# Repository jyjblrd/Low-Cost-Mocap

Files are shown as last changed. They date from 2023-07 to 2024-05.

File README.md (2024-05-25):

# Low Cost Mocap (for drones)

### A general purpose motion capture system built from the ground up, used to autonomously fly multiple drones indoors

## YouTube Video
Watch this for information about the project & a demo!
[https://youtu.be/0ql20JKrscQ?si=jkxyOe-iCG7fa5th](https://youtu.be/0ql20JKrscQ?si=jkxyOe-iCG7fa5th)

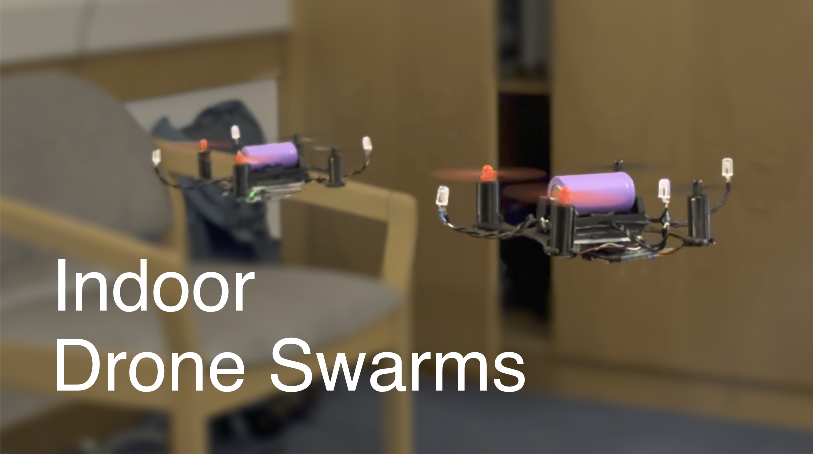
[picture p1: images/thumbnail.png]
[](https://youtu.be/0ql20JKrscQ?si=jkxyOe-iCG7fa5th)

## Architectural Diagram
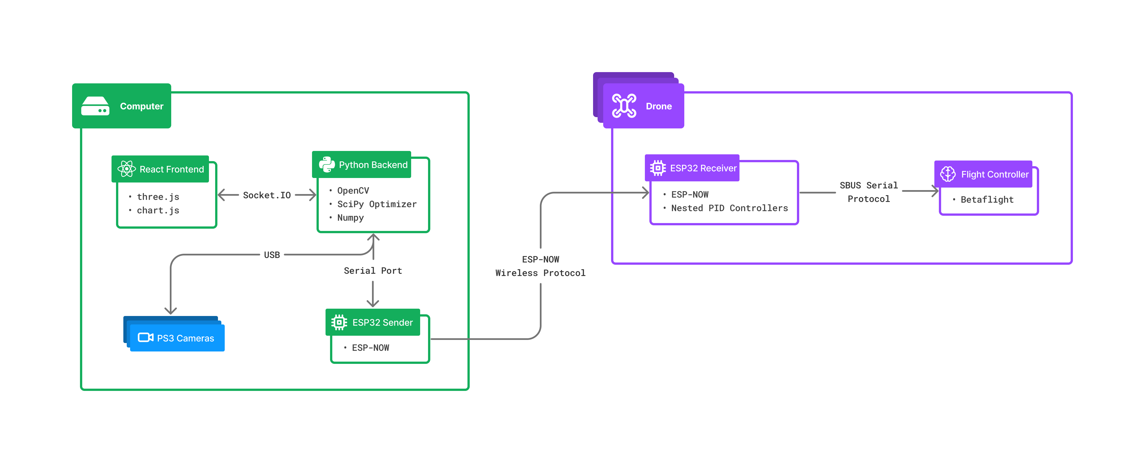
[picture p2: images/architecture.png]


## Dependencies
Install the pseyepy python library: [https://github.com/bensondaled/pseyepy](https://github.com/bensondaled/pseyepy)

This project requires the sfm (structure from motion) OpenCV module, which requires you to compile OpenCV from source[^1]. This is a bit of a pain, but these links should help you get started: [SFM dependencies](https://docs.opencv.org/4.x/db/db8/tutorial_sfm_installation.html) [OpenCV module installation guide](https://github.com/opencv/opencv_contrib/blob/master/README.md)

[^1]: ⚠️ The experimental [`no-cv-sfm`](https://github.com/jyjblrd/Low-Cost-Mocap/tree/no-cv-sfm) branch removes this OpenCV-SFM dependency, however it is *completely* untested. It is recommended to first try use the `main` branch which is tested, however feedback and bug reports on the `no-cv-sfm` branch are greatly appreciated. 

install npm and yarn

## Runing the code

From the computer_code directory Run `yarn install` to install node dependencies 

Then run `yarn run dev` to start the webserver. You will be given a url view the frontend interface.

In another terminal window, run `python3 api/index.py` to start the backend server. This is what receives the camera streams and does motion capture computations.

## Documentation
The documentation for this project is admittedly pretty lacking, if anyone would like to put type definitions in the Python code that would be amazing and probably go a long way to helping the readability of the code. Feel free to also use the [discussion](https://github.com/jyjblrd/Mocap-Drones/discussions) tab to ask questions.

My blog post has some more information about the drones & camera: [joshuabird.com/blog/post/mocap-drones](https://joshuabird.com/blog/post/mocap-drones)

[This post](https://github.com/jyjblrd/Low-Cost-Mocap/discussions/11#discussioncomment-9380283) by gumby0q explains how `camera_params.json` can be calculated for your cameras.

## "Inside-Out" Multi-Agent Tracking (SLAM)
This motion capture system is an "outside-in" system, with external cameras tracking objects within a fixed space. There are also "inside-out" systems which use cameras on the drones/robots to determine their locations, not requiring any external infrastructure. 

My undergraduate dissertation presents such a system, which is capable of localizing multiple agents within a world in real time using purely visual data, with state-of-the-art performance. Check it out here: [https://github.com/jyjblrd/distributed_visual_SLAM](https://github.com/jyjblrd/distributed_visual_SLAM)

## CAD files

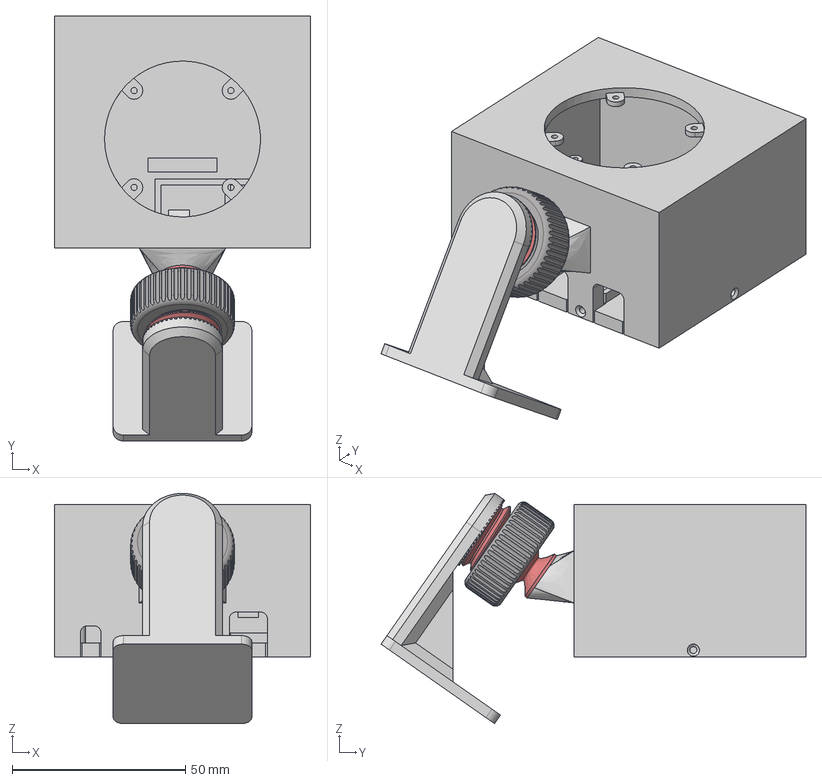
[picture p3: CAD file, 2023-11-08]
3d_files/camera.step
74.0 x 122.7 x 66.4 mm
Screw_V3
Ball_v3
Base_V3

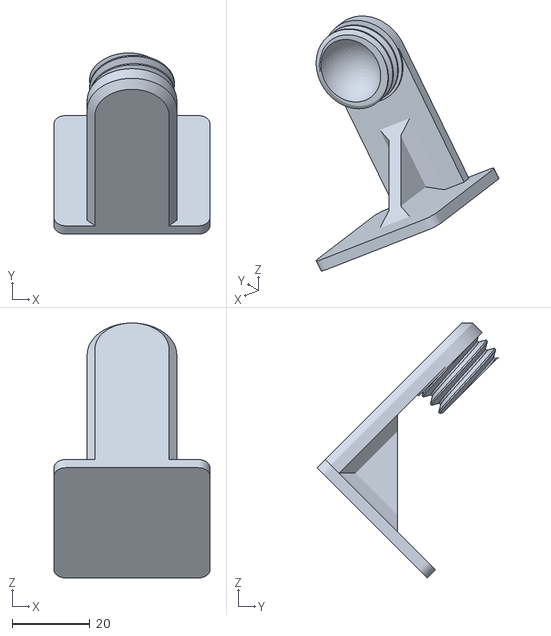
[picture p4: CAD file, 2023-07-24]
3d_files/camera_arm.stl
40.0 x 46.5 x 65.4

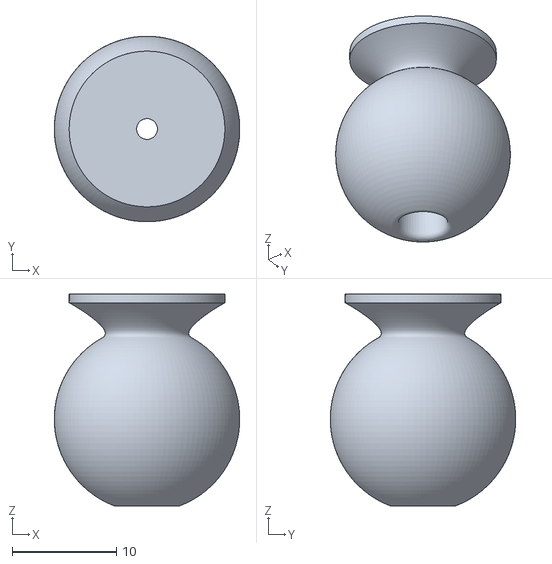
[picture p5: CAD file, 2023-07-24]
3d_files/camera_ball.stl
17.8 x 17.8 x 20.3

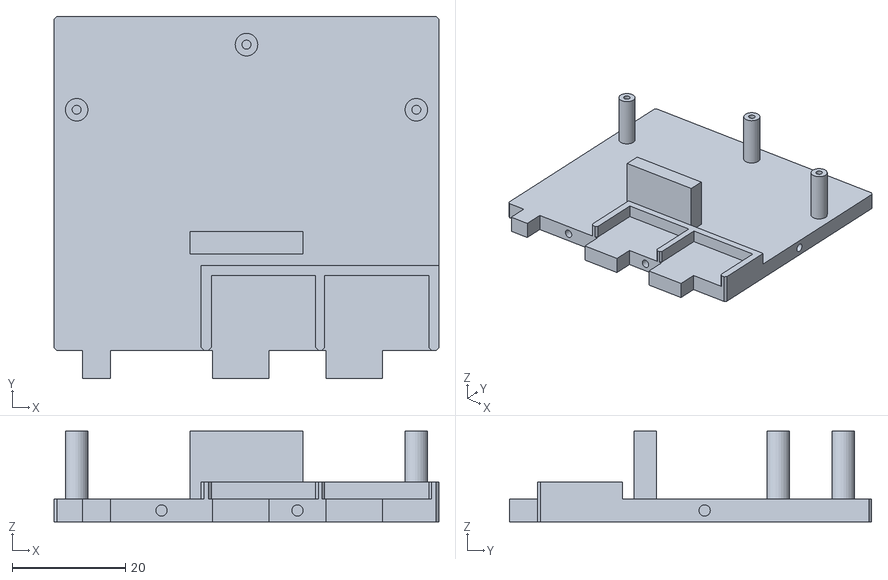
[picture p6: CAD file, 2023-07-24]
3d_files/camera_bottom_body.stl
68.0 x 64.0 x 16.0

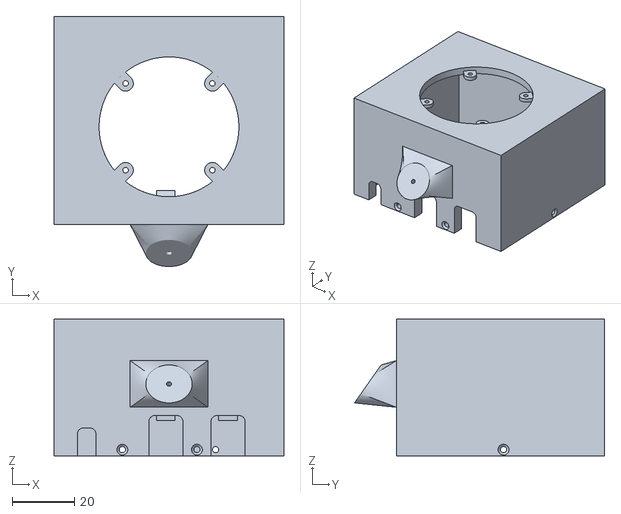
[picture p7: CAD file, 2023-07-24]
3d_files/camera_top_body.stl
74.0 x 80.5 x 44.0

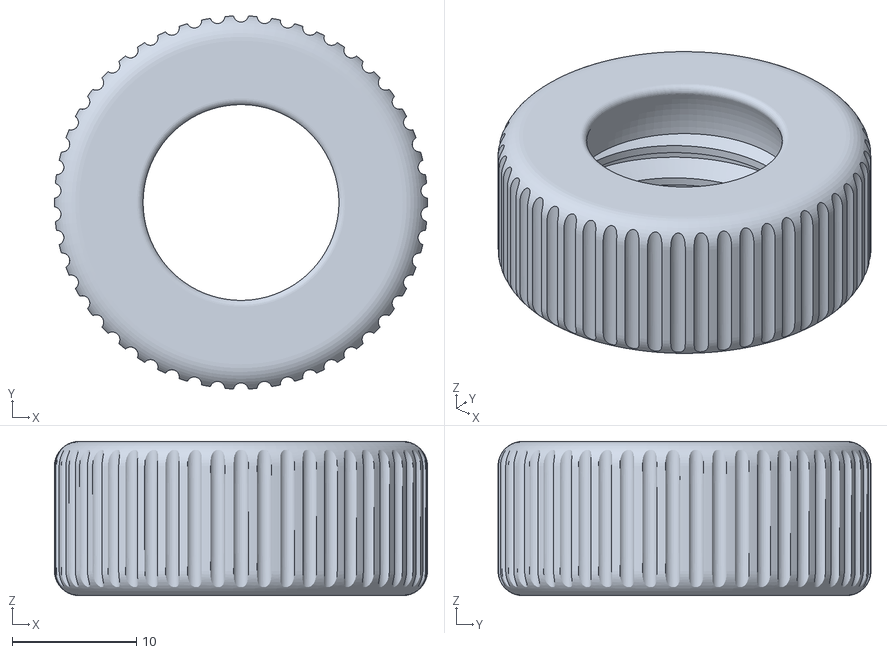
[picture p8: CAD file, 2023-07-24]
3d_files/camera_screw.stl
30.0 x 30.0 x 12.4

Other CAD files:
3d_files/camera.f3z

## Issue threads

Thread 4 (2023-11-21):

Remove cv.sfm dependency

jyjblrd, 2023-11-21:
This project depends on the OpenCV SFM (structure from motion) module, which requires you to build OpenCV from source. This is a huge pain, especially since we only use three simple functions from the module: `fundamentalFromProjections`, `essentialFromFundamental`, and `motionFromEssential`.

It should be very easy to reimplement these functions in python by looking at the module source code, and this would remove `cv.sfm` as a dependancy, making the project a lot more accessible.

SANTHOSH-MAMIDISETTI, 2023-11-22:
@jyjblrd  , Could you link where those functions are present in the [OpenCV](https://github.com/opencv/opencv) repo , I would like to have a look and start

jyjblrd, 2023-11-22:
Hey @SANTHOSH-MAMIDISETTI, you can find the occurrences [here](https://github.com/search?q=repo%3Ajyjblrd%2FMocap-Drones%20cv.sfm&type=code). It would be amazing if you can do this!

The source code for the sfm module is [here](https://github.com/opencv/opencv_contrib/tree/4.x/modules/sfm), and [heres](https://github.com/search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) an example of searching up the implementation of the `fundimentalFromProjections` function.

NightHawk32, 2023-11-29:
@jyjblrd could you provide test data of **camera1_image_points** and **camera2_image_points** like used [here](https://github.com/jyjblrd/Mocap-Drones/blob/7857ac0c0918948846a084a2c50841a76bc385dd/computer_code/api/index.py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)?
If possible the output of **F** and **E** would also be great. I am not entirely sure what the camera points look like. Additionally the test data would help to compare the openCV implementation of essentialFromFundamental to the python version.

jyjblrd, 2024-05-22:
Resolved by [https://github.com/jyjblrd/Low-Cost-Mocap/pull/42](https://github.com/jyjblrd/Low-Cost-Mocap/pull/42), which has been pulle into the [`no-cv-sfm`](https://github.com/jyjblrd/Low-Cost-Mocap/tree/no-cv-sfm) branch. However, this code is currently untested – test cases will need to be written before this issue can be closed.

high993, 2024-09-10:
Hey, @jyjblrd I have an amazing project in the works for 3D Markerless Human-Mocap using AI Models, that's very similar to your project.  I plan on pushing the project to github some time in the next days or weeks. In the course of making it, I learned that to avoid using opencv sfm some concessions must be made, for starters, fundamental matrix generators like RANSAC and LMEDS need a minimum number of points (8) to solve its position (or 7 if you make a few assumption's). I circumvented this by running my extrinsic calibration off of a large checker pattern placed in the center of the scene. However since I haven't made the IR filter modifications to the camera and I'm running the cameras in the res.LARGE (640x480) configuration, I'm not sure if this solution will work for you due to the compute overhead.  Also, I plan on making a YT vid explaining my code and I felt like that a proper reference to yourself was in order. Id be happy to hash out the details of the absence of opencv sfm after its published.

Cheers!
Adam,

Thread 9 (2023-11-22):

Serial Port needs to be configured

Gadgeteering, 2023-11-22:
When running api/index.py the serial port need to be configure to the serial controlling the quadcopter line 21 otherwise you get the error below

`serial.serialutil.SerialException: [Errno 2] could not open port /dev/cu.usbserial-02X2K2GE: [Errno 2] No such file or directory: '/dev/cu.usbserial-02X2K2GE'`

jyjblrd, 2023-11-22:
Yeah, that should definitely be configured some other way. Perhaps a command line argument or even a dropdown on the front end.

AliHusseinAlmoussawi, 2024-08-14:
Hello, is it necessary to configure the serial port to serial device controlling the quadcopter in order to run the command api/index.py?? Also I want to ask if this step is necessary for the cameras to stream and display at the frontend because I have run the frontend, but there is no displaying for the cameras.

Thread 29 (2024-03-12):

python3 api\index.py failed

Blaise-wig, 2024-03-12:
Hello, when I run python3 api\index.py, I get this error

(DroneControl) C:\Users\Victus\anaconda3\envs\DroneControl\Mocap-Drones-main\computer_code>python api\index.py
 * Serving Flask app 'index'
 * Debug mode: on
WARNING: This is a development server. Do not use it in a production deployment. Use a production WSGI server instead.
 * Running on http://127.0.0.1:3001
Press CTRL+C to quit
 * Restarting with stat
Traceback (most recent call last):
  File "C:\Users\Victus\anaconda3\envs\DroneControl\Mocap-Drones-main\computer_code\api\index.py", line 22, in <module>
    ser = serial.Serial("COM12", 115200, write_timeout=1, )
  File "C:\Users\Victus\anaconda3\envs\DroneControl\lib\site-packages\serial\serialwin32.py", line 33, in __init__
    super(Serial, self).__init__(*args, **kwargs)
  File "C:\Users\Victus\anaconda3\envs\DroneControl\lib\site-packages\serial\serialutil.py", line 244, in __init__
    self.open()
  File "C:\Users\Victus\anaconda3\envs\DroneControl\lib\site-packages\serial\serialwin32.py", line 64, in open
    raise SerialException("could not open port {!r}: {!r}".format(self.portstr, ctypes.WinError()))
serial.serialutil.SerialException: could not open port 'COM12': PermissionError(13, 'Access is denied.', None, 5)

I connected the esp32 to COM12 and made sure no other program is using the port. I have been trying to resolve this for two days now. can anyone help?

jyjblrd, 2024-03-12:
`PermissionError(13, 'Access is denied.', None, 5)`
 have you tried running with sudo? ie. `sudo python3 api\index.py`

jyjblrd, 2024-03-12:
Also make sure that your arduino ide / whatever you are using to program the ESP32 is closed, because it could also be connecting to the port.

Blaise-wig, 2024-03-13:
I'm on windows. But I ran it as administrator. I also closed the arduino IDE but the error still persisted.

clennpillo, 2024-05-26:
weird windows permission problem, I gave up windows and tried WSL, it worked.

clennpillo, 2024-06-08:
I was lately trying to run the code on windows10, and solved this permission problem, here is the detail.

if you are quite sure you serial port is not occupied by another program which is the situation in my case, but you still ran into the weird permissionerror 13 problem, you may try these steps.

first, turn off the reloader function of Flask-SocketIO, as flask-socketio might use your serial port which caused the permission problem.

second, create a unique thread for pyserial to operate serial port.

here is the code i use

`
app = Flask(__name__)
socketio = SocketIO(app, cors_allowed_origins='*', async_mode='threading')

serial_lock = threading.Lock()
ser = None

def serial_worker():
    global ser
    try:
        with serial_lock:
            ser = serial.Serial("COM5", 1000000, write_timeout=1)
            while True:
                data = ser.read(100)  # 示例串口读取操作
                if data:
                    print(f"Received data: {data}")
    except Exception as e:
        print(f"Serial exception: {e}")
`

`
if __name__ == '__main__':

    serial_thread = threading.Thread(target=serial_worker)
    serial_thread.daemon = True  # 让线程在主程序退出时自动结束
    serial_thread.start()

    socketio.run(app, port=3001, debug=True, use_reloader=False)
`

Closed 2024-07-12.

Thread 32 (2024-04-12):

error compiling cython file

986164283, 2024-04-12:
hello
I got an error when I try to install python setup.py install. I'm on Ubuntu 22. the main error:

Error compiling Cython file:
------------------------------------------------------------
...
        # init context
        print("about to init")
        try:
            ps3eye_init()
        except Exception as exc:
            print exc
                  ^
------------------------------------------------------------

pseyepy/cameras.pyx:245:18: Syntax error in simple statement list
Traceback (most recent call last):
  File "/root/pseyepy-master/setup.py", line 76, in <module>
    ext_modules=cythonize(extensions),)
                ^^^^^^^^^^^^^^^^^^^^^
  File "///anaconda3/lib/python3.11/site-packages/Cython/Build/Dependencies.py", line 1154, in cythonize
    cythonize_one(*args)
  File "//anaconda3/lib/python3.11/site-packages/Cython/Build/Dependencies.py", line 1321, in cythonize_one
    raise CompileError(None, pyx_file)
Cython.Compiler.Errors.CompileError: pseyepy/cameras.pyx

The above is where the error is reported

I hope someone can help  and give me more information

Thanks in advance.

jyjblrd, 2024-04-12:
Hi, that seems to be a bug in the pseyepy library: github.com/bensondaled/pseyepy/

Something is going wrong in the `ps3eye_init()` function and the exception isnt being printed because it should be `print(exc)` not `print exc`. I would change this line so you actually can see what the error is to properly debug the problem, and then reinstall the library.

jyjblrd, 2024-04-12:
This issue looks to be the same issue that you had: [https://github.com/bensondaled/pseyepy/issues/15](https://github.com/bensondaled/pseyepy/issues/15)

986164283, 2024-04-15:
Hi, have you modified it? I downloaded and reinstalled and still got the same prompt。

jyjblrd, 2024-04-15:
Hi, you should reinstall the pseyepy library, modify the code as I mentioned, and try run it again. Or you could pull [this branch](https://github.com/bensondaled/pseyepy/pull/18) which looks to solve the problem.

986164283, 2024-04-16:
Hello, after following the modifications you mentioned, the problem has been solved, thank you.

林玮
***@***.***

&nbsp;

------------------&nbsp;原始邮件&nbsp;------------------
发件人:                                                                                                                        "jyjblrd/Low-Cost-Mocap"                                                                                    ***@***.***&gt;;
发送时间:&nbsp;2024年4月15日(星期一) 晚上10:38
***@***.***&gt;;
***@***.******@***.***&gt;;
主题:&nbsp;Re: [jyjblrd/Low-Cost-Mocap] error compiling cython file (Issue #32)

Hi, you should reinstall the pseyepy library, modify the code as I mentioned, and try run it again. Or you could pull this branch which looks to solve the problem.

—
Reply to this email directly, view it on GitHub, or unsubscribe.
You are receiving this because you authored the thread.Message ID: ***@***.***&gt;

luislglp, 2024-05-31:
Thanks for mentioning the checklist, jyjblrd.
I still had some issues with the pseyepy library even after following zalo's checklist to install on Windows 11 (VS 2022).
Maybe this is too basic, but not sure if we need somehow to install the camera drivers first.
I downloaded the CL-Eye driver, tested the cameras and after that the pseyepy library worked fine.

Closed 2024-04-23.

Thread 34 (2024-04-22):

An issue about pose calibration

zwq-88, 2024-04-22:
Hi, when we clicked on the Collect points for camera pose calibration button, we used one infrared LED to move through the experimental space to collect points. However, the effect of camera pose calibration was poor. Can you please provide some specific operational details for camera pose calibration?
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

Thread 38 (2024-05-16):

ESP32 code is for CP2104 or CH9102 ?

clennpillo, 2024-05-16:
hello, when I choose to buy ESP32 board, I found the link given in the article didn't specify the serial port type, say there are two types in the link, CP2104 and CH9102, which one should I buy ?

thanks .

jyjblrd, 2024-05-16:
It shouldn't matter, those are just the usb --> uart chips they use. Both should work exactly the same.

clennpillo, 2024-05-17:
thanks for the reply.

Closed 2024-05-17.

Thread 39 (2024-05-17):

"python3 api\index.py" successful, but the video stream is not visible on the UI.

cultist123, 2024-05-17:
File "/Users/apple/Documents/2 工作空间/git/Low-Cost-Mocap-main/computer_code/api/index.py", line 55, in gen
    frames = cameras.get_frames()
  File "/Users/apple/Documents/2 工作空间/git/Low-Cost-Mocap-main/computer_code/api/helpers.py", line 138, in get_frames
    frames = self._camera_read()
  File "/Users/apple/Documents/2 工作空间/git/Low-Cost-Mocap-main/computer_code/api/helpers.py", line 72, in _camera_read
    frames[i] = np.rot90(frames[i], k=self.camera_params[i]["rotation"])
ValueError: assignment destination is read-only

The source code may have issues.

jyjblrd, 2024-05-17:
That is strange. Try adding the line `frame[i] = frame[i].copy()` before the line that is causing the error.

cultist123, 2024-05-21:
The issue has been resolved, and the software can now be used by simply plugging in multiple cameras. It is recommended to have all hardware connections completed before running the software.

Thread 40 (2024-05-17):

Operating System and Version Inquiry Regarding Compatibility Issues with Pseyepy Library

cultist123, 2024-05-17:
May I ask if you are using Ubuntu or Windows system, and what version? Your tutorial does not provide this information. The pseyepy library is very old, causing many backend configuration mismatches and incompatibilities, which has consumed a lot of my time.

jyjblrd, 2024-05-17:
Hi, I am using MacOS 14. Pseyepy worked for me, but it might have some issues with Windows.

cultist123, 2024-05-21:
I am also using macOS 14, but I have an M2 chip with ARM architecture. Are you using an Intel chip? I'm not sure if this will affect the project.

jyjblrd, 2024-05-22:
I am also using a M2 Mac.

cultist123, 2024-05-24:
That's great, thank you! I'll go and try it again.

Closed 2024-05-24.

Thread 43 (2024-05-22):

Battery 9A seems way too big for the boards

clennpillo, 2024-05-22:
hi,

I found 9A battery is too big for the boards, already ruined ESP32 receiver, and F3 EVO is very hot while working, I'm not sure if I had done it right though.

jyjblrd, 2024-05-22:
The battery shouldn't be blowing up your boards.
I connected the battery to the F3 EVO flight controller, and used the 3.3v output from that board to power the ESP32.

Perhaps you installed the battery with the wrong polarity (ie. mixed up +/-).. There is no protection against this and even doing it once can destroy the boards.

clennpillo, 2024-05-23:
Maybe you're right, anyway I just used a smaller battery that is 1A, hope it works well.

jyjblrd, 2024-05-23:
Amperage does not have any impact on if a battery will blow up a board, it's the voltage that kills a board. Single cell Li-ion batteries are always around 3.7v (because of chemistry), which the flight controller is built to handle.

The amp-hour (Ah) rating of a battery is just how long it will last. It's like how putting a larger fuel tank in your car won't damage the engine... if that makes sense.

Just don't reverse the polarity and you'll be fine.

clennpillo, 2024-05-24:
I guess my board blowed up was because I once reversed the polarity. I always think Amperage does not have any impact on if a battery will blow up a board, if I use 3.7V it's always ok.

one question is that why the battery has a paramter of 9A, what does this indicates ?

jyjblrd, 2024-05-24:
The battery I recommend is the 18350 type (18mm * 35mm). The one I used has a voltage of 3.7v, a capacity of 1100mAh, and a max current if 9A. The voltage is self explanatory.

1100mAh means that it can output 1100milliamps (at 3.7v) for 1 hour (this works out to 1.1Ah * 3.7v = 4.07watthours.

9A means that the max current it can provide is 9 amps, or 9A*3.7V = 33.3 watts.

clennpillo, 2024-05-30:
I used the 9A battery again, the F3 board was again much hotter than the small battery, I then found this picture below in your video, it showed that you used two resistances on the board, is this the reason that the current on your board is not that high.

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

jyjblrd, 2024-05-30:
No, those resistors are a voltage divider to measure the voltage level of the battery (which I never wrote the code for).

After reversing the polarity of the F3 board, it will be permanently damaged, you may need to buy a new one.

Closed 2024-05-23.

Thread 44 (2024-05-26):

ESP32 receiver soldering with F3 EVO

clennpillo, 2024-05-26:
hi,

I got a problem that I dont' know how to soldering ESP32 receiver to F3 EVO board, I watched the video but there was no details about this.

My betaflight is as follow
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

### ESP32 receiver soldering
I suppose four terminals need to be soldered.
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

### F3 EVO soldering
I know how to solder power terminals, but for signals, because my betaflight showing that UART2's serial function is enabled as in the screen shot above, I guess I need to use UART2's two terminals, one is TX, another is RX, however, I couldn't find any article or video that explain which terminals are for UART1, UART2, UART3.
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

I tried to connect in the way above before soldering, but it turned out the motors won't start, so I think there might be some problem here.

Can you tell me where can I find this information about UART1,2,3 's corresponding terminals, and can you give me your sodering picture ?

cultist123, 2024-05-26:
Although I haven't solved this problem for you, I have done some research on it. The F3 board does not have the corresponding communication pins, so you can only solder it directly to the STM32 chip. I suggest you refer to the STM32 chip diagram as shown below, and solder it as demonstrated in the video.
![Uploading 截屏2024-05-26 20.43.44.png…]()

jyjblrd, 2024-05-26:
You actually need to connect the ESP32 to the UART 3. UART 1 is used by the usb interface (i think?) and UART 2 is used by the onboard RC receiver (useful to keep around for manual flying / debug purposes).

[This location in the video](https://www.youtube.com/watch?v=0ql20JKrscQ&t=157s) shows the UART 3 RX pin to solder to. You can then tell betaflight to use UART 3 as the RC signal. It isn't the best solution, a better flight controller that actually breaks out the extra UART as a solderable pin would be better.

clennpillo, 2024-05-27:
Thanks for jyjblrd and cultist123's replies which helps me out.

now I get it, the right terminal is on STM32 instead of F3 board. I just tried to connect as follows.

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

on the ESP32 receiver side, I deployed React frontend, python backend ESP32 sender and ESP32 receiver, the receiver was able to send data via sbus and I could see the logs while I click buttons at React frontend, I changed some code slightly to let the code run even if the cameras are not ready yet. The screenshot is what I see in Arduino running ESP32 receiver.
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

I clicked arm at frontend, but motors still won't start. Any suggestions ?

clennpillo, 2024-05-27:
I did some debug, when I type status command in CLI of betaflight, I got RXLOSS which means the receiver is not ready, didn't operation connecting ESP32 to STM32 make a good receiver for the F3 EVO board ?

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

jyjblrd, 2024-05-27:
Yes, RX loss means that the flight controller is not receiving any RC signal from the ESP32.
1. Are you sure that the cable is connected correctly to the flight controller's pin? It is a very very small pin as I'm sure you know.
2. Is the ESP 32 receiver's code configured to send the data out of the correct digital out pin?
3. Is Betaflight correctly configured to receive the SBus data from the ESP 32?

clennpillo, 2024-05-27:
Turned out I didn't make the tiny pin from STM32 connection right.

I did it again and now the RXLOSS problem is solved, so I guess I know the correct pair that should be soldered between F3 EVO and ESP32 receiver, however, I tried many many times to solder the tiny pin and failed many many times, that's really the most difficult part in this project, till now I 'm still trying.

jyjblrd, 2024-05-27:
Yeah, a better flight controller which actually breaks out the extra UART would make things a lot easier. Better yet, the esp32 could be the flight controller itself (one core receiving and decoding messages, another core controlling the motors).

clennpillo, 2024-05-27:
This is a great project that exactly meet our needs, so I tried my best to use what hardware and software you use in order to understand this project, after making this right, we gonna make changes and upgrade,etc.  Really appreciate what you have done.

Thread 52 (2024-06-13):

About IR markers powering

clennpillo, 2024-06-13:
hi, jyjblrd

I have a question about IR markers powering.

My IR marker 's rated voltage is 1.5V，I got three IR markers attached to my drone.

And I have 3.7V battery on the drone， how should I power the IR markers ?

I have now connected three infrared lights in series and powered the series circuit with the 3.7V battery. The lights do turn on, but I am not sure if this is the correct approach. Can you show me your approach ?

jyjblrd, 2024-06-24:
I used a led calculator to determine what resistor to use. eg: https://ledcalculator.net/

Closed 2024-07-12.

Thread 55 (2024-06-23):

How to write embedded code.

cultist123, 2024-06-23:
I want to know how you write code for Arduino and how you choose and implement communication protocols. I want to implement similar functionality on another embedded board but don't know where to start.

jyjblrd, 2024-06-24:
I would recommend using the arduino IDE if you are a beginner, there are a lot of libraries and it supports arduino, esp8266, and esp32 boards.

Closed 2024-07-12.

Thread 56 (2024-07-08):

Openning 2 or more webcams is not possible ?

clennpillo, 2024-07-08:
hi jyjblrd,

I ran into a problem that I cannot open 2 or more webcams at the same time on my computer. Opening first webcam is ok, but openning the second one fails. This happens when I plug in 2 or more webcams on my USB hub which connects to one USB3.0 port of my computer, however, if I plug in 2 webcams on 2 seperate USB ports of my computer, everything works fine, the error information is as follows.

when using openCV,
ret, frame = cap.read() always gets a False for ret which means openning failure

I also tried VLC, the error was
capture device might be in use

This is some information for reference.
laptop: Thinkpad L14
os: windows10 home edition 22H2
USB hub: external power supply and USB3.0 support

Can you tell me how you connect 4 cameras to your computer in your instance ?

jyjblrd, 2024-07-12:
Hi,

Has this issue been solved? (and if so, please let others know how you fixed it in case others have the same issue!)

I vaguely remember having issues if I plugged too many cameras into the same cheap USB hub, but had no issues with my powered usb hub.

clennpillo, 2024-07-16:
I used night vision usb cameras, I never tried pseye. Pseye python library must have dealt with multi-camera problem as long as you use a powered hub.

I use Windows 10,  I got 2 USB controller ports on my computer, one connected a cheap usb hub, plugged in two cameras, the other connected a powered usb hub, plugged in other two cameras.

I adjusted camera parameter in code that make resolution to 320x240, this make sure you don't have bandwidth issue.

I started 4 individual processes to read camera frames, started a websocket server, the camera readers sent frame data to websocket server, I added some code to read from websocket server to get frames in helpers.py.

jyjblrd, 2024-07-16:
Hmm, not sure about how windows handles multiple webcams but I assume it should be fine? Unfortunately I can't help much as I don't have a windows computer or multiple webcams.

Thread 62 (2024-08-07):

Socket.IO communication issue

lurz01, 2024-08-07:
Hello,

Thank you for contributing such a powerful open-source project. I followed your instructions to run the project and found that the video stream is transmitted normally, but the Socket.IO communication is not working properly. Have you encountered a similar issue, or could you provide some troubleshooting ideas? I would greatly appreciate it.

deyoyow, 2024-09-30:
Hello lurz, may i ask is your flask running on the index.py

`if __name__ == '__main__':
    socketio.run(app, port=3001, debug=True)`

 Mine seems to kept re-opening the COM port if the parameter set to `debug=True`
 and while `debug=False` resolves the error, the camera is seems to be not running (FPS = 0)
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

cultist123, 2025-01-12:
the solution is to connect four cameras

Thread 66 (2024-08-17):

[BUG] Issue with running the index.py file

thesis09, 2024-08-17:
**Describe the bug**
the pseyepy is having issue says :

File "M:\Low-Cost-Mocap-main\computer_code\api\index.py", line 1, in <module>
    from helpers import camera_pose_to_serializable, calculate_reprojection_errors, bundle_adjustment, Cameras, triangulate_points
  File "M:\Low-Cost-Mocap-main\computer_code\api\helpers.py", line 12, in <module>
    from pseyepy import Camera
ModuleNotFoundError: No module named 'pseyepy'

but after some research i found the repo and cloned it but still i am encountering the same issue
when i type (pip install .)
it gives me this new issue:

Processing m:\low-cost-mocap-main\pseyepy
  Preparing metadata (setup.py) ... error
  error: subprocess-exited-with-error

  × python setup.py egg_info did not run successfully.
  │ exit code: 1
  ╰─> [31 lines of output]
      M:\Low-Cost-Mocap-main\pseyepy\setup.py:48: UserWarning: Setup params not yet fully tested for Windows.
        warnings.warn('Setup params not yet fully tested for Windows.')
      C:\Users\MAG\AppData\Local\Programs\Python\Python311\Lib\site-packages\Cython\Compiler\Main.py:381: FutureWarning: Cython directive 'language_level' not set, using '3str' for now (Py3). This has changed from earlier releases! File: M:\Low-Cost-Mocap-main\pseyepy\pseyepy\cameras.pyx
        tree = Parsing.p_module(s, pxd, full_module_name)

      Error compiling Cython file:
      ------------------------------------------------------------
      ...
              # init context
              print("about to init")
              try:
                  ps3eye_init()
              except Exception as exc:
                  print exc
                        ^
      ------------------------------------------------------------

      pseyepy\cameras.pyx:245:18: Syntax error in simple statement list
      Traceback (most recent call last):
        File "<string>", line 2, in <module>
        File "<pip-setuptools-caller>", line 34, in <module>
        File "M:\Low-Cost-Mocap-main\pseyepy\setup.py", line 76, in <module>
          ext_modules=cythonize(extensions),)
                      ^^^^^^^^^^^^^^^^^^^^^
        File "C:\Users\MAG\AppData\Local\Programs\Python\Python311\Lib\site-packages\Cython\Build\Dependencies.py", line 1154, in cythonize
          cythonize_one(*args)
        File "C:\Users\MAG\AppData\Local\Programs\Python\Python311\Lib\site-packages\Cython\Build\Dependencies.py", line 1321, in cythonize_one
          raise CompileError(None, pyx_file)
      Cython.Compiler.Errors.CompileError: pseyepy/cameras.pyx
      Compiling pseyepy/cameras.pyx because it changed.
      [1/1] Cythonizing pseyepy/cameras.pyx
      [end of output]

  note: This error originates from a subprocess, and is likely not a problem with pip.
error: metadata-generation-failed

× Encountered error while generating package metadata.
╰─> See above for output.

note: This is an issue with the package mentioned above, not pip.
hint: See above for details

after fixing it , still i am unable to run the backend
Can you please help me in this ...

deyoyow, 2024-09-25:
Hey, are you able to run the pseyepy stand alone?

If not please try this to run it independently first with the code provided at the repo:

`from pseyepy import Camera, Display

c = Camera() # initialize a camera
d = Display(c) # begin the display`

It works fine for me after following the instructions at
[https://github.com/bensondaled/pseyepy/issues/22](url)

Cheers,
Deyo

deyoyow, 2024-09-30:
Hey, sorry for the broken link you could copy the raw text instead.

[Here](https://github.com/bensondaled/pseyepy/issues/22)

Cheers, Deyo

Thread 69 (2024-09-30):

Camera capture broken when trying to start camera stream

deyoyow, 2024-09-30:
So I tried to run 'python api/index.py' and when I started the stream it looks like this:
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

I've succesful in tackling the COM port error in Windows following this  #29
camera works fine if I try with the original pseyepy command

Is it really necessary to have 4 cameras plugged in for the stream to work as mentioned in #39?

Regards,
Deyo

jyjblrd, 2024-10-01:
Are there any errors printed by the python program?

Does the python program identify the correct number of cameras? (see this line: https://github.com/jyjblrd/Low-Cost-Mocap/blob/8ac4d4107fda026d787d5e197f0dcbe6257b2720/computer_code/api/helpers.py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)

cultist123, 2024-11-21:
I encountered the same issue as you, and it requires connecting four cameras to resolve it.

RayInst, 2025-03-03:
The ps3eye driver doesn't support the simultaneous use of more than two ps3eye cameras very well.

deyoyow, 2025-03-06:
> I encountered the same issue as you, and it requires connecting four cameras to resolve it.

Do you use 4 USB Cable with a hub into a single port? or do you mind explaining your setup for it to work?

Regards
Deyo

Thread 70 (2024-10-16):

Some details for the project

jackwei86, 2024-10-16:
When the software and hardware are ready， I open the url:  127.0.0.1:5173 and see the Ctrl UI .

Step 1: Click the "Camera Stream Start" button and see the  camera images

Step 2: Click the "Collect points for camera pose calibration Start" button to prepare for Calculating camera pose

Step 3:After collecting some points , Click the "Calculate camera pose with XXX points" to generate Camera Poses Matrics.

What about the "To World Matrix" and how to generate it?
Is that need to measure the distances between the cameras and get the coordinate information of the cameras in the real world?

I use 3 led lights(A B  C ). The distances between each other light are 0.086m（A to B） 0.082m(B to C ) 0.070m(A to C ).  I found the code in helper.py
`
def locate_objects(object_points, errors):
    dist1 = 0.095
    dist2 = 0.15
`
I don't know how to modify the code . Can you supply any suggestion?

jackwei86, 2024-10-29:
@jyjblrd Any suggestion for my post?  Much appreciated for your help.

Closed 2024-10-29.

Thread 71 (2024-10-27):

[BUG] bug_issue_title

youxiao888, 2024-10-27:
Hello, when there are two or more capture points in the current image, how can this code ensure that the points on one image correspond one-to-one with the points on another image to solve the fundamental matrix between the two cameras

code:
`@socketio.on("calculate-camera-pose")
def calculate_camera_pose(data):
    cameras = Cameras.instance()
    image_points = np.array(data["cameraPoints"])
    image_points_t = image_points.transpose((1, 0, 2))

    camera_poses = [{
        "R": np.eye(3),
        "t": np.array([[0],[0],[0]], dtype=np.float32)
    }]
    for camera_i in range(0, cameras.num_cameras-1):
        camera1_image_points = image_points_t[camera_i]
        camera2_image_points = image_points_t[camera_i+1]
        not_none_indicies = np.where(np.all(camera1_image_points != None, axis=1) & np.all(camera2_image_points != None, axis=1))[0]
        camera1_image_points = np.take(camera1_image_points, not_none_indicies, axis=0).astype(np.float32)
        camera2_image_points = np.take(camera2_image_points, not_none_indicies, axis=0).astype(np.float32)

        F, _ = cv.findFundamentalMat(camera1_image_points, camera2_image_points, cv.FM_RANSAC, 1, 0.99999)
        E = cv.sfm.essentialFromFundamental(F, cameras.get_camera_params(0)["intrinsic_matrix"], cameras.get_camera_params(1)["intrinsic_matrix"])`

jyjblrd, 2024-10-27:
When collecting data for the camera pose calibration, you must only have one point in the room. If there is only one point seen by each camera, the point association is trivial.

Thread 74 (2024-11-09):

[BUG] bug_issue_title

youxiao888, 2024-11-09:
Hello, it seems that my socket is stuck in HTTP long polling, and my FPS will not automatically update and display unless you click the stop button next to Camera Stream and then click start again. The FPs value will only automatically update on the webpage. I have tried many Flask versions and socket client versions, but it seems that they do not work

youxiao888, 2024-11-09:
Uploading 2946_1731168495.mp4…

youxiao888, 2024-11-09:
https://github.com/user-attachments/assets/19a6a438-1d0f-4b98-a819-a584cbd3490b

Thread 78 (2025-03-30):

IR floodlight ring

Mohamed-magdy22, 2025-03-30:
Do you know if the IR floodlight is essential for use with the camera? I plan to use only one drone with IR LED markers, as I cannot obtain the IR floodlight ring in my country.

thanks.

janlishak, 2025-04-20:
Hi, the IR floodlights are optional. However, they might make testing and debugging a little easier. Here's a list of things that will be affected.

Camera intrinsics calculation
After you put the IR passthrough filter (floppy disk) on the cameras, they won't be able to capture the checkerboard pattern. You would need to illuminate them with the IR floodlight. To calibrate without the IR floodlight, you'll have to do the calibration without the filters, which might introduce a small inaccuracy since the filters can distort the image a little, but it probably won't be a problem. To sum up, make sure you get the intrinsics of the camera before you put the filters on.

Everything will be dark
Since there will not be any IR light in your room, it might be harder to orient the cameras. Just make sure none of the cameras are obscured by furniture or other objects in the room because you won't be able to actually see it in the image.

Retroreflective markers
As far as I can tell, Joshua intended to use the IR floodlights with retroreflective markers. The advantage would be that the markers wouldn't need to be powered because they would reflect the light from the IR floodlights. But if you want to use IR LEDs, as Joshua did, it might be actually better to turn the floodlights off to minimize noise.

Mohamed-magdy22, 2025-04-21:
Thank you very much—I truly appreciate your support.

 I have one more question: Is it necessary to calibrate the cameras using a traditional chessboard pattern, or is it also acceptable to use infrared (IR) markers as an alternative method for calibration?

janlishak, 2025-04-22:
Hi, using the checkerboard pattern is the standard way to estimate the intrinsics of a camera. It is already implemented in OpenCV, and the steps are discussed in this thread: https://github.com/jyjblrd/Low-Cost-Mocap/discussions/11

In my case, I was able to use some values I found in the thread. All PS3 cameras should be quite similar, so if you're lucky, you might be able to use someone else's values if they had a similar setup. However, getting the actual values for your own cameras is definitely recommended. With incorrect intrinsics, you'll have trouble estimating the poses when running the project.

Mohamed-magdy22, 2025-04-23:
Thank you very much—I truly appreciate your support.

Closed 2025-05-03.

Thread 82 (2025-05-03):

camera-calipration & esp (sender , reciver ) code

Mohamed-magdy22, 2025-05-03:
I’m currently facing an issue during the camera calibration process when using a single IR marker. After the initial calibration attempt, I received the following output:

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

Upon repeating the calibration process a second time, the following error occurred:

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

I’ve attached the resulting camera-parameters file generated after calibration. However, I’m unsure about the purpose of the camera-parameters-copy file that was also created. Could you kindly clarify its function and whether it’s related to the error?

Request:
I’d appreciate any guidance on resolving this calibration issue and understanding the role of the camera-parameters-copy file.

Part 2: ESP32 Communication Issue
I'm also experiencing issues getting ESP32 sender and receiver modules to communicate reliably using ESP-NOW. Despite multiple attempts, they fail to connect consistently.

Could someone kindly share:

A verified sender and receiver code known to work with ESP-NOW.

Clear steps to successfully upload both sketches to ESP32 boards, including any required board settings or library installations.

This would be incredibly helpful to ensure the communication is properly established and stable.

Appreciation:
I really appreciate any guidance or working examples the community can share. Thank you in advance for your time and support.

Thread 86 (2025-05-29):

What an amazing work

mohamdev, 2025-05-29:
Hi!

Thank you for this amazing work, done by an obviously passionate man :-)

Actually I work a lot on low cost human motion capture with CV on embedded devices.

I believe that we can autonomosly control a drone using embedded camera and human pose observations. For instance, we could potentially control the drone to permanently follow a human, or to perform certain actions given a human pose.

Are such features present in the current version? What do you think about such ideas?

I will take a deep look to the repo whenever I can and try to contribute. Thanks again for this work, and don't hesitate to contact me if interested ;)

Best regards

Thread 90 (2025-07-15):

[BUG] Two sources of inaccuracy

paddyobrien, 2025-07-15:
I've done some work using the code from this project so I wanted to give back a little and share a couple of issues I found in case they are useful to others. Upstreaming my fixes isn't really feasible so I'll just describe them here.

1. Making the image square prior to undistorting causes inaccurate undistortion and ultimately inaccurate tracking, I found the results were off by about 4mm and distances between two points on the same object changed as the object moved around the scene. These lines [here](https://github.com/jyjblrd/Low-Cost-Mocap/blob/main/computer_code/api/helpers.py#L73-L74) should probably be flipped, or the "make_square" call just removed entirely as it doesn't really contribute anything.
2. During pose estimation the wrong intrinsic matrices are used when getting the essential matrix, [here](https://github.com/jyjblrd/Low-Cost-Mocap/blob/main/computer_code/api/index.py#L247) the intrinsics for camera 0 and 1 are always used rather than `camera_i` and `camera_i + 1`.
3. Also during pose estimation a call is made to "triangulate_points" [here](https://github.com/jyjblrd/Low-Cost-Mocap/blob/main/computer_code/api/index.py#L254), this always passes two camera poses for the two cameras that are having their Fundamental matrix calculated. Within "triangulate_points" the projection matrices for these cameras are generated, however the wrong intrinsic matrices get used for this because "triangulate_points" assumes that the full set of cameras is always passed to it and matches the intrinsic matrices using the array index of the camera pose [here](https://github.com/jyjblrd/Low-Cost-Mocap/blob/main/computer_code/api/helpers.py#L307). The fix I landed on for this was switch to passing projection matrices into `triangulate_points` rather than poses. This  involves quite a few changes around the codebase.

I have made a bunch of other changes which can be found here: https://github.com/paddyobrien/weccap. I've tested this work fairly rigorously and found that the motion tracking is now accurate to a fraction of a mm at the scales I use!

Thanks again to the original author for all the great work and for sharing publicly.

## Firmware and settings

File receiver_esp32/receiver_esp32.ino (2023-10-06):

#include <esp_now.h>
#include <esp_wifi.h>
#include <WiFi.h>
#include <ArduinoJson.h>
#include <PID_v1.h>
#include <stdint.h>
#include <EEPROM.h>
#include "sbus.h"

#define batVoltagePin 34
#define MAX_VEL 100
#define ROTOR_RADIUS 0.0225
#define Z_GAIN 0.7

#define DRONE_INDEX 1

#define EEPROM_SIZE 4

unsigned long lastPing;

bfs::SbusTx sbus_tx(&Serial1, 33, 32, true, false);
bfs::SbusData data;

bool armed = false;
unsigned long timeArmed = 0;

StaticJsonDocument<1024> json;

int xTrim = 0, yTrim = 0, zTrim = 0, yawTrim = 0;

double groundEffectCoef = 28, groundEffectOffset = -0.035;

// nested pid loops
// outer: position pid loop
// inner: velocity pid loop
// velocity pid loop sends accel setpoint to flight controller
double xPosSetpoint = 0, xPos = 0;
double yPosSetpoint = 0, yPos = 0;
double zPosSetpoint = 0, zPos = 0;
double yawPosSetpoint = 0, yawPos, yawPosOutput;

double xyPosKp = 1, xyPosKi = 0, xyPosKd = 0;
double zPosKp = 1.5, zPosKi = 0, zPosKd = 0;
double yawPosKp = 0.3, yawPosKi = 0.1, yawPosKd = 0.05;

double xVelSetpoint, xVel, xVelOutput;
double yVelSetpoint, yVel, yVelOutput;
double zVelSetpoint, zVel, zVelOutput;

double xyVelKp = 0.2, xyVelKi = 0.03, xyVelKd = 0.05;
double zVelKp = 0.3, zVelKi = 0.1, zVelKd = 0.05;

PID xPosPID(&xPos, &xVelSetpoint, &xPosSetpoint, xyPosKp, xyPosKi, xyPosKd, DIRECT);
PID yPosPID(&yPos, &yVelSetpoint, &yPosSetpoint, xyPosKp, xyPosKi, xyPosKd, DIRECT);
PID zPosPID(&zPos, &zVelSetpoint, &zPosSetpoint, zPosKp, zPosKi, zPosKd, DIRECT);
PID yawPosPID(&yawPos, &yawPosOutput, &yawPosSetpoint, yawPosKp, yawPosKi, yawPosKd, DIRECT);

PID xVelPID(&xVel, &xVelOutput, &xVelSetpoint, xyVelKp, xyVelKi, xyVelKd, DIRECT);
PID yVelPID(&yVel, &yVelOutput, &yVelSetpoint, xyVelKp, xyVelKi, xyVelKd, DIRECT);
PID zVelPID(&zVel, &zVelOutput, &zVelSetpoint, zVelKp, zVelKi, zVelKd, DIRECT);


unsigned long lastLoopTime = micros();
unsigned long lastSbusSend = micros();
float loopFrequency = 2000.0;
float sbusFrequency = 50.0;

#if DRONE_INDEX == 0
  uint8_t newMACAddress[] = { 0xC0, 0x4E, 0x30, 0x4B, 0x61, 0x3A };
#elif DRONE_INDEX == 1
  uint8_t newMACAddress[] = { 0xC0, 0x4E, 0x30, 0x4B, 0x80, 0x3B };
#endif

// callback function that will be executed when data is received
void OnDataRecv(const uint8_t *mac, const uint8_t *incomingData, int len) {
  // Serial.println((char*)incomingData);
  DeserializationError err = deserializeJson(json, (char *)incomingData);

  if (err) {
    Serial.print("failed to parse json");
    return;
  }

  if (json.containsKey("pos") && json.containsKey("vel")) {
    xPos = json["pos"][0];
    yPos = json["pos"][1];
    zPos = json["pos"][2];
    yawPos = json["pos"][3];

    xVel = json["vel"][0];
    yVel = json["vel"][1];
    zVel = json["vel"][2];
  } else if (json.containsKey("armed")) {
    if (json["armed"] != armed && json["armed"]) {
      timeArmed = millis();
    }
    armed = json["armed"];
  } else if (json.containsKey("setpoint")) {
    xPosSetpoint = json["setpoint"][0];
    yPosSetpoint = json["setpoint"][1];
    zPosSetpoint = json["setpoint"][2];
  } else if (json.containsKey("pid")) {
    xPosPID.SetTunings(json["pid"][0], json["pid"][1], json["pid"][2]);
    yPosPID.SetTunings(json["pid"][0], json["pid"][1], json["pid"][2]);
    zPosPID.SetTunings(json["pid"][3], json["pid"][4], json["pid"][5]);
    yawPosPID.SetTunings(json["pid"][6], json["pid"][7], json["pid"][8]);

    xVelPID.SetTunings(json["pid"][9], json["pid"][10], json["pid"][11]);
    yVelPID.SetTunings(json["pid"][9], json["pid"][10], json["pid"][11]);
    zVelPID.SetTunings(json["pid"][12], json["pid"][13], json["pid"][14]);

    groundEffectCoef = json["pid"][15];
    groundEffectOffset = json["pid"][16];
  } else if (json.containsKey("trim")) {
    xTrim = json["trim"][0];
    yTrim = json["trim"][1];
    zTrim = json["trim"][2];
    yawTrim = json["trim"][3];
  }

  lastPing = micros();
}

void resetPid(PID &pid, double min, double max) {
  pid.SetOutputLimits(0.0, 1.0); 
  pid.SetOutputLimits(-1.0, 0.0);
  pid.SetOutputLimits(min, max);
}

void setup() {
  // Initialize Serial Monitor
  Serial.begin(115200);

  sbus_tx.Begin();
  data.failsafe = false;
  data.ch17 = true;
  data.ch18 = true;
  data.lost_frame = false;
  for (int i = 500; i > 172; i--) {
    for (int j = 0; j < 16; j++) {
      data.ch[j] = i;
    }
    Serial.println(i);
    sbus_tx.data(data);
    sbus_tx.Write();
  }

  // Set device as a Wi-Fi Station
  wifi_init_config_t cfg = WIFI_INIT_CONFIG_DEFAULT();
  esp_wifi_init(&cfg);
  esp_wifi_set_mode(WIFI_MODE_STA);
  esp_wifi_set_mac(WIFI_IF_STA, &newMACAddress[0]);
  esp_wifi_set_bandwidth(WIFI_IF_STA, WIFI_BW_HT20);
  esp_wifi_set_storage(WIFI_STORAGE_RAM);
  esp_wifi_set_ps(WIFI_PS_NONE);
  //esp_wifi_set_channel(1, WIFI_SECOND_CHAN_NONE);
  esp_wifi_start();

  // Init ESP-NOW
  if (esp_now_init() != ESP_OK) {
    Serial.println("Error initializing ESP-NOW");
    return;
  }
  esp_wifi_config_espnow_rate(WIFI_IF_STA, WIFI_PHY_RATE_24M);
  esp_wifi_start();

  // Once ESPNow is successfully Init, we will register for recv CB to
  // get recv packer info
  esp_now_register_recv_cb(OnDataRecv);


  xPosPID.SetMode(AUTOMATIC);
  yPosPID.SetMode(AUTOMATIC);
  zPosPID.SetMode(AUTOMATIC);
  yawPosPID.SetMode(AUTOMATIC);
  xVelPID.SetMode(AUTOMATIC);
  yVelPID.SetMode(AUTOMATIC);
  zVelPID.SetMode(AUTOMATIC);
  
  // Sample rate is determined by main loop
  xPosPID.SetSampleTime(0);
  yPosPID.SetSampleTime(0);
  zPosPID.SetSampleTime(0);
  yawPosPID.SetSampleTime(0);
  xVelPID.SetSampleTime(0);
  yVelPID.SetSampleTime(0);
  zVelPID.SetSampleTime(0);

  xPosPID.SetOutputLimits(-MAX_VEL, MAX_VEL);
  yPosPID.SetOutputLimits(-MAX_VEL, MAX_VEL);
  zPosPID.SetOutputLimits(-MAX_VEL, MAX_VEL);
  yawPosPID.SetOutputLimits(-1, 1);
  xVelPID.SetOutputLimits(-1, 1);
  yVelPID.SetOutputLimits(-1, 1);
  zVelPID.SetOutputLimits(-1, 1);

  EEPROM.begin(EEPROM_SIZE);

  // xTrim = EEPROM.read(0);
  // yTrim = EEPROM.read(1);
  // zTrim = EEPROM.read(2);
  // yawTrim = EEPROM.read(3);

  lastPing = micros();
  lastLoopTime = micros();
  lastSbusSend = micros();
}

void loop() {
  while (micros() - lastLoopTime < 1e6 / loopFrequency) { yield(); }
  lastLoopTime = micros();

  if (micros() - lastPing > 2e6) {
    armed = false;
  }

  if (armed) {
    data.ch[4] = 1800;
  } else {
    data.ch[4] = 172;
    resetPid(xPosPID, -MAX_VEL, MAX_VEL);
    resetPid(yPosPID, -MAX_VEL, MAX_VEL);
    resetPid(zPosPID, -MAX_VEL, MAX_VEL);
    resetPid(yawPosPID, -1, 1);
    resetPid(xVelPID, -1, 1);
    resetPid(yVelPID, -1, 1);
    resetPid(zVelPID, -1, 1);
  }

  xPosPID.Compute();
  yPosPID.Compute();
  zPosPID.Compute();
  yawPosPID.Compute();

  xVelPID.Compute();
  yVelPID.Compute();
  zVelPID.Compute();
  int xPWM = 992 + (xVelOutput * 811) + xTrim;
  int yPWM = 992 + (yVelOutput * 811) + yTrim;
  int zPWM = 992 + (Z_GAIN * zVelOutput * 811) + zTrim;
  int yawPWM = 992 + (yawPosOutput * 811) + yawTrim;
  double groundEffectMultiplier = 1 - groundEffectCoef*pow(((2*ROTOR_RADIUS) / (4*(zPos-groundEffectOffset))), 2);
  zPWM *= max(0., groundEffectMultiplier);
  zPWM = armed && millis() - timeArmed > 100 ? zPWM : 172;
  data.ch[0] = -yPWM;
  data.ch[1] = xPWM;
  data.ch[2] = zPWM;
  data.ch[3] = yawPWM;

  if (micros() - lastSbusSend > 1e6 / sbusFrequency) {
    lastSbusSend = micros();
    // Serial.printf("PWM x: %d, y: %d, z: %d, yaw: %d\nPos x: %f, y: %f, z: %f, yaw: %f\n", xPWM, yPWM, zPWM, yawPWM, xVel, yVel, zPos, yawPos);
    // Serial.printf("Setpoint x: %f, y: %f, z: %f\n", xVelSetpoint, yVelSetpoint, zVelSetpoint);
    // Serial.printf("Pos x: %f, y: %f, z: %f\n", xVel, yVel, zPos);
    //Serial.printf("Output x: %f, y: %f, z: %f\n", xVelOutput, yVelOutput, zVelOutput);

    sbus_tx.data(data);
    sbus_tx.Write();
  }
}

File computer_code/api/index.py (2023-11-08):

from helpers import camera_pose_to_serializable, calculate_reprojection_errors, bundle_adjustment, Cameras, triangulate_points
from KalmanFilter import KalmanFilter

from flask import Flask, Response, request
import cv2 as cv
import numpy as np
import json
from scipy import linalg

from flask_socketio import SocketIO
import copy
import time
import serial
import threading
from ruckig import InputParameter, OutputParameter, Result, Ruckig
from flask_cors import CORS
import json

serialLock = threading.Lock()

ser = serial.Serial("/dev/cu.usbserial-02X2K2GE", 1000000, write_timeout=1, )

app = Flask(__name__)
CORS(app, supports_credentials=True)
socketio = SocketIO(app, cors_allowed_origins='*')

cameras_init = False

num_objects = 2

@app.route("/api/camera-stream")
def camera_stream():
    cameras = Cameras.instance()
    cameras.set_socketio(socketio)
    cameras.set_ser(ser)
    cameras.set_serialLock(serialLock)
    cameras.set_num_objects(num_objects)
    
    def gen(cameras):
        frequency = 150
        loop_interval = 1.0 / frequency
        last_run_time = 0
        i = 0

        while True:
            time_now = time.time()

            i = (i+1)%10
            if i == 0:
                socketio.emit("fps", {"fps": round(1/(time_now - last_run_time))})

            if time_now - last_run_time < loop_interval:
                time.sleep(last_run_time - time_now + loop_interval)
            last_run_time = time.time()
            frames = cameras.get_frames()
            jpeg_frame = cv.imencode('.jpg', frames)[1].tostring()

            yield (b'--frame\r\n'
                b'Content-Type: image/jpeg\r\n\r\n' + jpeg_frame + b'\r\n')

    return Response(gen(cameras), mimetype='multipart/x-mixed-replace; boundary=frame')

@app.route("/api/trajectory-planning", methods=["POST"])
def trajectory_planning_api():
    data = json.loads(request.data)

    waypoint_groups = [] # grouped by continuious movement (no stopping)
    for waypoint in data["waypoints"]:
        stop_at_waypoint = waypoint[-1]
        if stop_at_waypoint:
            waypoint_groups.append([waypoint[:3*num_objects]])
        else:
            waypoint_groups[-1].append(waypoint[:3*num_objects])
    
    setpoints = []
    for i in range(0, len(waypoint_groups)-1):
        start_pos = waypoint_groups[i][0]
        end_pos = waypoint_groups[i+1][0]
        waypoints = waypoint_groups[i][1:]
        setpoints += plan_trajectory(start_pos, end_pos, waypoints, data["maxVel"], data["maxAccel"], data["maxJerk"], data["timestep"])

    return json.dumps({
        "setpoints": setpoints
    })

def plan_trajectory(start_pos, end_pos, waypoints, max_vel, max_accel, max_jerk, timestep):
    otg = Ruckig(3*num_objects, timestep, len(waypoints))  # DoFs, timestep, number of waypoints
    inp = InputParameter(3*num_objects)
    out = OutputParameter(3*num_objects, len(waypoints))

    inp.current_position = start_pos
    inp.current_velocity = [0,0,0]*num_objects
    inp.current_acceleration = [0,0,0]*num_objects

    inp.target_position = end_pos
    inp.target_velocity = [0,0,0]*num_objects
    inp.target_acceleration = [0,0,0]*num_objects

    inp.intermediate_positions = waypoints

    inp.max_velocity = max_vel*num_objects
    inp.max_acceleration = max_accel*num_objects
    inp.max_jerk = max_jerk*num_objects

    setpoints = []
    res = Result.Working
    while res == Result.Working:
        res = otg.update(inp, out)
        setpoints.append(copy.copy(out.new_position))
        out.pass_to_input(inp)

    return setpoints

@socketio.on("arm-drone")
def arm_drone(data):
    global cameras_init
    if not cameras_init:
        return
    
    Cameras.instance().drone_armed = data["droneArmed"]
    for droneIndex in range(0, num_objects):
        serial_data = {
            "armed": data["droneArmed"][droneIndex],
        }
        with serialLock:
            ser.write(f"{str(droneIndex)}{json.dumps(serial_data)}".encode('utf-8'))
        
        time.sleep(0.01)

@socketio.on("set-drone-pid")
def arm_drone(data):
    serial_data = {
        "pid": [float(x) for x in data["dronePID"]],
    }
    with serialLock:
        ser.write(f"{str(data['droneIndex'])}{json.dumps(serial_data)}".encode('utf-8'))
        time.sleep(0.01)

@socketio.on("set-drone-setpoint")
def arm_drone(data):
    serial_data = {
        "setpoint": [float(x) for x in data["droneSetpoint"]],
    }
    with serialLock:
        ser.write(f"{str(data['droneIndex'])}{json.dumps(serial_data)}".encode('utf-8'))
        time.sleep(0.01)

@socketio.on("set-drone-trim")
def arm_drone(data):
    serial_data = {
        "trim": [int(x) for x in data["droneTrim"]],
    }
    with serialLock:
        ser.write(f"{str(data['droneIndex'])}{json.dumps(serial_data)}".encode('utf-8'))
        time.sleep(0.01)


@socketio.on("acquire-floor")
def acquire_floor(data):
    cameras = Cameras.instance()
    object_points = data["objectPoints"]
    object_points = np.array([item for sublist in object_points for item in sublist])

    tmp_A = []
    tmp_b = []
    for i in range(len(object_points)):
        tmp_A.append([object_points[i,0], object_points[i,1], 1])
        tmp_b.append(object_points[i,2])
    b = np.matrix(tmp_b).T
    A = np.matrix(tmp_A)

    fit, residual, rnk, s = linalg.lstsq(A, b)
    fit = fit.T[0]

    plane_normal = np.array([[fit[0]], [fit[1]], [-1]])
    plane_normal = plane_normal / linalg.norm(plane_normal)
    up_normal = np.array([[0],[0],[1]], dtype=np.float32)

    plane = np.array([fit[0], fit[1], -1, fit[2]])

    # https://math.stackexchange.com/a/897677/1012327
    G = np.array([
        [np.dot(plane_normal.T,up_normal)[0][0], -linalg.norm(np.cross(plane_normal.T[0],up_normal.T[0])), 0],
        [linalg.norm(np.cross(plane_normal.T[0],up_normal.T[0])), np.dot(plane_normal.T,up_normal)[0][0], 0],
        [0, 0, 1]
    ])
    F = np.array([plane_normal.T[0], ((up_normal-np.dot(plane_normal.T,up_normal)[0][0]*plane_normal)/linalg.norm((up_normal-np.dot(plane_normal.T,up_normal)[0][0]*plane_normal))).T[0], np.cross(up_normal.T[0],plane_normal.T[0])]).T
    R = F @ G @ linalg.inv(F)

    R = R @ [[1,0,0],[0,-1,0],[0,0,1]] # i dont fucking know why

    cameras.to_world_coords_matrix = np.array(np.vstack((np.c_[R, [0,0,0]], [[0,0,0,1]])))

    socketio.emit("to-world-coords-matrix", {"to_world_coords_matrix": cameras.to_world_coords_matrix.tolist()})
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

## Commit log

2023-07-24 bundle adjustment working
    [Ball_v3 v2.stl, Body1.stl, Screw_V3 v3.stl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]
2023-07-27 migrated to vite
    [ball.stl]
2023-07-31 multi camera working threejs
2023-08-08 camera pose calculation works with multiple points
2023-08-08 multipoint triangulation working (buggy)
    [index.py]
2023-08-14 kalman filtering (thanks chatgpt)
2023-08-27 drone working (added pos chart, frame rate limiting, relaible connections)
2023-08-29 auto heading compensation and other stuff
    [tiny drone spacer.stl]
2023-08-29 pid wasnt changing (bruh)
2023-08-30 do positioning based on velocity not pos
2023-09-02 too much filtering is bad! also added filter resets that dont work
    [index.py]
2023-09-02 graph drone setpoints, add preset movements, add Kp for position pid controller and better pid resetting
    [receiver_esp32.ino]
2023-09-03 trajectory planning
    [tiny drone spacer.stl]
2023-09-03 added pos outer pid loop
2023-09-04 landing and ground effect compensation
2023-09-07 fps, better cam calibration,
    [tiny drone spacer.stl]
2023-09-15 not working - dual drones
    [index.py, sender_esp32.ino]
2023-10-05 fix camera params
2023-10-05 actually make kalman and filters reset on rerun
    [index.py]
2023-10-05 significantly improve object detection (dual drone using extra led, create more root objects, better finding of objects from many incorrect points)
2023-10-05 fucking sick camera calibration
2023-10-06 fix filtering
2023-11-08 move files around
    [Body1.stl, arm1.stl, arm2.stl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]
2023-11-08 add camera f3z and step files
    [camera.f3z, camera.step]
